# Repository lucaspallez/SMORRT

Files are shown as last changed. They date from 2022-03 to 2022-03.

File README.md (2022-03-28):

# SMORRT
Smart Management of Rocket Recovery and Telemetry

Avionics PCB for High-Power Rocketry

Embedded Software for this board available here: https://github.com/lucaspallez/SMORRT_Software
Compatible Ground Station PCB: https://github.com/lucaspallez/GRUND

## Features
- Computation: Teensy 4.1
- Telemetry: RFM95W LoRa Module (with SMA connector)
- IMU: MPU 6050 Breakout
- Barometer: BMP 280 Breakout
- GPS: Ublox NEO-M8J Module (with SMA connector)
- Data logging: 1Mbit FRAM IC + Teensy SD Card slot with locking screw
- Power Output: 4 MOSFET Pyro outputs with E-match detection, 2 Servo compatible (via PWM)
- Battery Management: 2x 1s Li-Ion Battery chargers
- Power Inputs: 2x Redundant 1s Li-Ion Battery connectors + 1x 12V Battery connector for power
- Arming: 1x Main external arm switch + 1x Power out external arm switch
- Status Indicators: 5x User programmable LEDs, 1x Buzzer
- Battery voltage readings

## Changes planned:
- Reduce the physical size to fit in smaller diameter rockets

## Documentation

Designed with KiCAD 5.5

TODO

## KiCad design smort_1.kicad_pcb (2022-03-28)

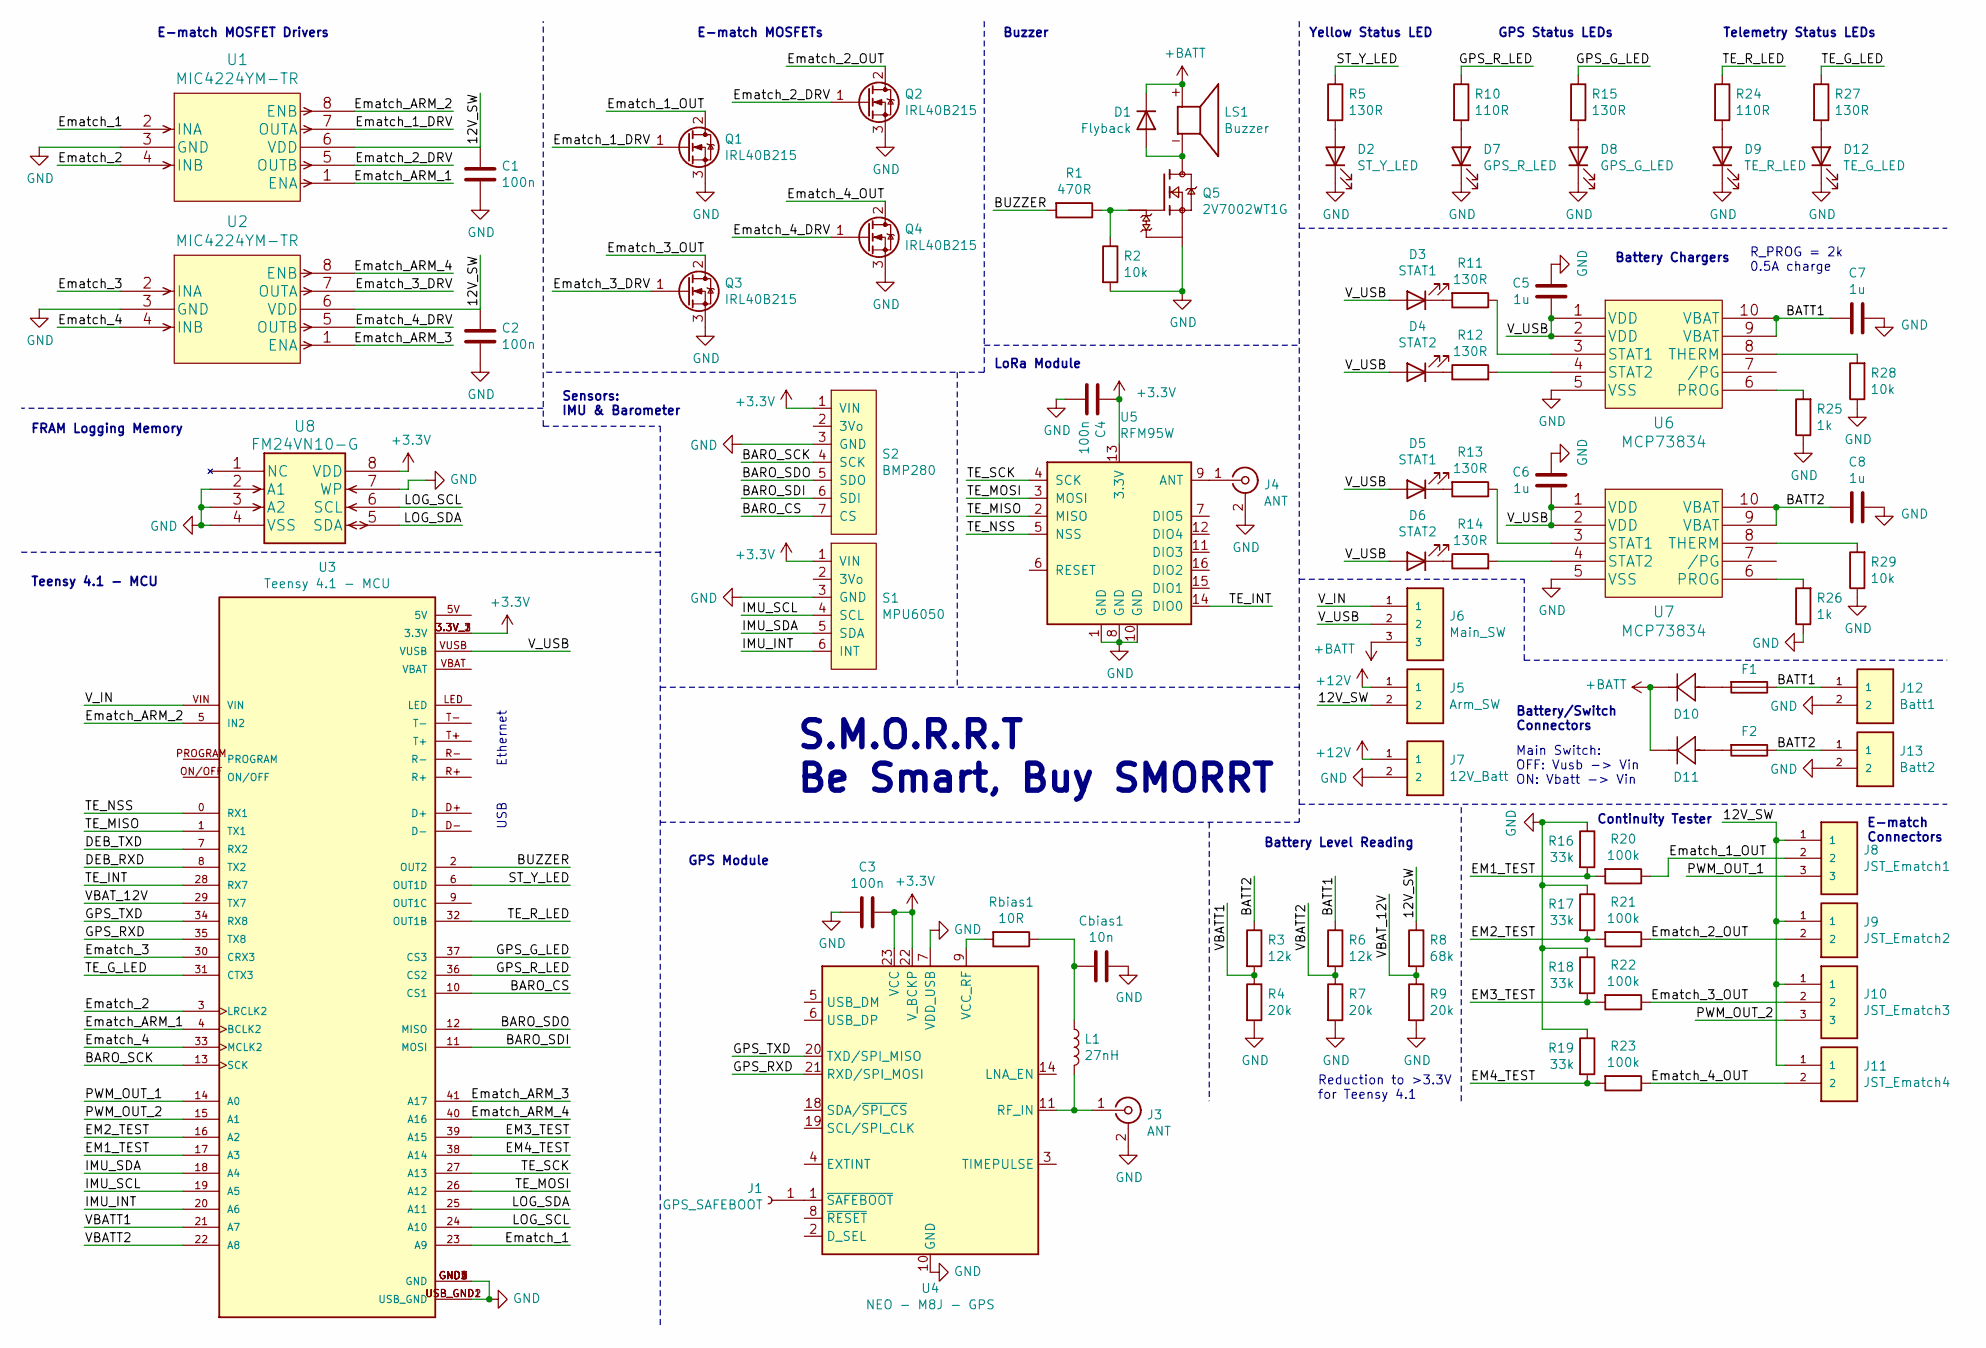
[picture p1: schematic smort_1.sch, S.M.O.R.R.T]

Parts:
C1, C2, C3, C4: 100n; C_0805_2012Metric
C5, C6, C7, C8: 1u; C_0805_2012Metric
Cbias1: 10n; C_0805_2012Metric
D1: Flyback; D_SOD-123F
D2: ST_Y_LED; LED_0805_2012Metric_Pad1.15x1.40mm_HandSolder
D3, D5: STAT1; LED_0805_2012Metric_Pad1.15x1.40mm_HandSolder
D4, D6: STAT2; LED_0805_2012Metric_Pad1.15x1.40mm_HandSolder
D7: GPS_R_LED; LED_0805_2012Metric_Pad1.15x1.40mm_HandSolder
D8: GPS_G_LED; LED_0805_2012Metric_Pad1.15x1.40mm_HandSolder
D9: TE_R_LED; LED_0805_2012Metric_Pad1.15x1.40mm_HandSolder
D10: BATT1; LSM115JE3&slash_TR13
D11: BATT2; LSM115JE3&slash_TR13
D12: TE_G_LED; LED_0805_2012Metric_Pad1.15x1.40mm_HandSolder
F1, F2: Fuse; Fuse_0805_2012Metric
J1: GPS_SAFEBOOT; PinHeader_1x01_P2.54mm_Vertical
J3, J4: ANT; LINX_CONSMA020.062-G
J5: Arm_SW; JST_S2B-PH-K-S(LF)(SN)
J6: Main_SW; JST_S3B-PH-K-S(LF)(SN)
J7: 12V_Batt; JST_S2B-PH-K-S(LF)(SN)
J8: JST_Ematch1; JST_S3B-PH-K-S(LF)(SN)
J9: JST_Ematch2; JST_S2B-PH-K-S(LF)(SN)
J10: JST_Ematch3; JST_S3B-PH-K-S(LF)(SN)
J11: JST_Ematch4; JST_S2B-PH-K-S(LF)(SN)
J12: Batt1; JST_S2B-PH-K-S(LF)(SN)
J13: Batt2; JST_S2B-PH-K-S(LF)(SN)
L1: 27nH; L_0805_2012Metric
LS1: Buzzer; CUI_CMI-9605IC-0380T; PARTREV 1.0
Q1, Q2, Q3, Q4: IRL40B215; TO-220F-3_Vertical
Q5: 2V7002WT1G; SOT65P220X100-3N; PARTREV 6
R1: 470R; R_0805_2012Metric
R2, R28, R29: 10k; R_0805_2012Metric
R3, R6: 12k; R_0805_2012Metric
R4, R7, R9: 20k; R_0805_2012Metric
R5, R11, R12, R13, R14, R15, R27: 130R; R_0805_2012Metric
R8: 68k; R_0805_2012Metric
R10, R24: 110R; R_0805_2012Metric
R16, R17, R18, R19: 33k; R_0805_2012Metric
R20, R21, R22, R23: 100k; R_0805_2012Metric
R25, R26: 1k; R_0805_2012Metric
Rbias1: 10R; R_0805_2012Metric
S1: MPU6050; MPU_6050_Breakout
S2: BMP280; BMP_280_Breakout
U1, U2: MIC4224YM-TR
U3: Teensy 4.1 - MCU; MODULE_DEV-16771; PARTREV 4.1
U4: NEO - M8J - GPS; ublox_NEO
U5: RFM95W; HOPERF_RFM9XW_SMD
U6, U7: MCP73834; MCP73834-NVI&slash_UN
U8: FM24VN10-G

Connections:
+3V3: C3.1, C4.1, S1.1 (VIN), S2.1 (VIN), U3.3.3V_1 (3.3V), U3.3.3V_2 (3.3V), U3.3.3V_3 (3.3V), U4.22 (V_BCKP), U4.23 (VCC), U5.13 (3.3V), U8.8 (VDD)
+12V: J5.1, J7.1
+BATT: D1.1 (K), D10.1, D11.1, J6.3, LS1.P
/12V_SW: C1.1, C2.1, J5.2, J8.1, J9.1, J10.1, J11.1, R8.1, U1.6 (VDD), U2.6 (VDD)
/BARO_CS: S2.7 (CS), U3.10 (CS1)
/BARO_SCK: S2.4 (SCK), U3.13 (SCK)
/BARO_SDI: S2.6 (SDI), U3.11 (MOSI)
/BARO_SDO: S2.5 (SDO), U3.12 (MISO)
/BATT1: C7.1, F1.1, J12.1, R6.1, U6.9 (VBAT), U6.10 (VBAT)
/BATT2: C8.1, F2.1, J13.1, R3.1, U7.9 (VBAT), U7.10 (VBAT)
/BUZZER: R1.2, U3.2 (OUT2)
/DEB_RXD: U3.8 (TX2)
/DEB_TXD: U3.7 (RX2)
/EM1_TEST: R16.2, R20.2, U3.17 (A3)
/EM2_TEST: R17.2, R21.2, U3.16 (A2)
/EM3_TEST: R18.2, R22.2, U3.39 (A15)
/EM4_TEST: R19.2, R23.2, U3.38 (A14)
/Ematch_1: U1.2 (INA), U3.23 (A9)
/Ematch_1_DRV: Q1.1 (G), U1.7 (OUTA)
/Ematch_1_OUT: J8.2, Q1.2 (D), R20.1
/Ematch_2: U1.4 (INB), U3.3 (LRCLK2)
/Ematch_2_DRV: Q2.1 (G), U1.5 (OUTB)
/Ematch_2_OUT: J9.2, Q2.2 (D), R21.1
/Ematch_3: U2.2 (INA), U3.30 (CRX3)
/Ematch_3_DRV: Q3.1 (G), U2.7 (OUTA)
/Ematch_3_OUT: J10.2, Q3.2 (D), R22.1
/Ematch_4: U2.4 (INB), U3.33 (MCLK2)
/Ematch_4_DRV: Q4.1 (G), U2.5 (OUTB)
/Ematch_4_OUT: J11.2, Q4.2 (D), R23.1
/Ematch_ARM_1: U1.1 (ENA), U3.4 (BCLK2)
/Ematch_ARM_2: U1.8 (ENB), U3.5 (IN2)
/Ematch_ARM_3: U2.1 (ENA), U3.41 (A17)
/Ematch_ARM_4: U2.8 (ENB), U3.40 (A16)
/GPS_G_LED: R15.1, U3.37 (CS3)
/GPS_RXD: U3.35 (TX8), U4.21 (RXD/SPI_MOSI)
/GPS_R_LED: R10.1, U3.36 (CS2)
/GPS_TXD: U3.34 (RX8), U4.20 (TXD/SPI_MISO)
/IMU_INT: S1.6 (INT), U3.20 (A6)
/IMU_SCL: S1.4 (SCL), U3.19 (A5)
/IMU_SDA: S1.5 (SDA), U3.18 (A4)
/LOG_SCL: U3.24 (A10), U8.6 (SCL)
/LOG_SDA: U3.25 (A11), U8.5 (SDA)
/PWM_OUT_1: J8.3, U3.14 (A0)
/PWM_OUT_2: J10.3, U3.15 (A1)
/ST_Y_LED: R5.1, U3.6 (OUT1D)
/TE_G_LED: R27.1, U3.31 (CTX3)
/TE_INT: U3.28 (RX7), U5.14 (DIO0)
/TE_MISO: U3.1 (TX1), U5.2 (MISO)
/TE_MOSI: U3.26 (A12), U5.3 (MOSI)
/TE_NSS: U3.0 (RX1), U5.5 (NSS)
/TE_R_LED: R24.1, U3.32 (OUT1B)
/TE_SCK: U3.27 (A13), U5.4 (SCK)
/VBATT1: R3.2, R4.1, U3.21 (A7)
/VBATT2: R6.2, R7.1, U3.22 (A8)
/VBAT_12V: R8.2, R9.1, U3.29 (TX7)
/V_IN: J6.1, U3.VIN
/V_USB: C5.1, C6.1, D3.2 (A), D4.2 (A), D5.2 (A), D6.2 (A), J6.2, U3.VUSB, U6.1 (VDD), U6.2 (VDD), U7.1 (VDD), U7.2 (VDD)
GND: C1.2, C2.2, C3.2, C4.2, C5.2, C6.2, C7.2, C8.2, Cbias1.2, D2.1 (K), D7.1 (K), D8.1 (K), D9.1 (K), D12.1 (K), J3.2 (Ext), J4.2 (Ext), J7.2, J12.2, J13.2, Q1.3 (S), Q2.3 (S), Q3.3 (S), Q4.3 (S), Q5.2, R2.2, R4.2, R7.2, R9.2, R16.1, R17.1, R18.1, R19.1, R25.1, R26.1, R28.1, R29.1, S1.3 (GND), S2.3 (GND), U1.3 (GND), U2.3 (GND), U3.GND1 (GND), U3.GND2 (GND), U3.GND3 (GND), U3.GND4 (GND), U3.GND5 (GND), U3.USB_GND1 (USB_GND), U3.USB_GND2 (USB_GND), U4.7 (VDD_USB), U4.10 (GND), U4.12 (GND), U4.13 (GND), U4.24 (GND), U5.1 (GND), U5.8 (GND), U5.10 (GND), U6.5 (VSS), U7.5 (VSS), U8.2 (A1), U8.3 (A2), U8.4 (VSS), U8.7 (WP)
unnamed: Cbias1.1, L1.1, Rbias1.1
unnamed: D1.2 (A), LS1.N, Q5.3
unnamed: D2.2 (A), R5.2
unnamed: D3.1 (K), R11.2
unnamed: D4.1 (K), R12.1
unnamed: D5.1 (K), R13.2
unnamed: D6.1 (K), R14.1
unnamed: D7.2 (A), R10.2
unnamed: D8.2 (A), R15.2
unnamed: D9.2 (A), R24.2
unnamed: D10.2, F1.2
unnamed: D11.2, F2.2
unnamed: D12.2 (A), R27.2
unnamed: J1.1, U4.1 (~SAFEBOOT)
unnamed: J3.1 (In), L1.2, U4.11 (RF_IN)
unnamed: J4.1 (In), U5.9 (ANT)
unnamed: Q5.1, R1.1, R2.1
unnamed: R11.1, U6.3 (STAT1)
unnamed: R12.2, U6.4 (STAT2)
unnamed: R13.1, U7.3 (STAT1)
unnamed: R14.2, U7.4 (STAT2)
unnamed: R25.2, U6.6 (PROG)
unnamed: R26.2, U7.6 (PROG)
unnamed: R28.2, U6.8 (THERM)
unnamed: R29.2, U7.8 (THERM)
unnamed: Rbias1.2, U4.9 (VCC_RF)

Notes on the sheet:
Telemetry Status LEDs
GPS Status LEDs
Yellow Status LED
E-match MOSFET Drivers
E-match MOSFETs
LoRa Module
Ethernet
USB
Teensy 4.1 - MCU
GPS Module
Battery Chargers
Main Switch: OFF: Vusb -> Vin ON: Vbatt -> Vin
Battery/Switch Connectors
Buzzer
Sensors: IMU & Barometer
R_PROG = 2k 0.5A charge
Battery Level Reading
Reduction to >3.3V for Teensy 4.1
FRAM Logging Memory
S.M.O.R.R.T Be Smart, Buy SMORRT
E-match Connectors
Continuity Tester

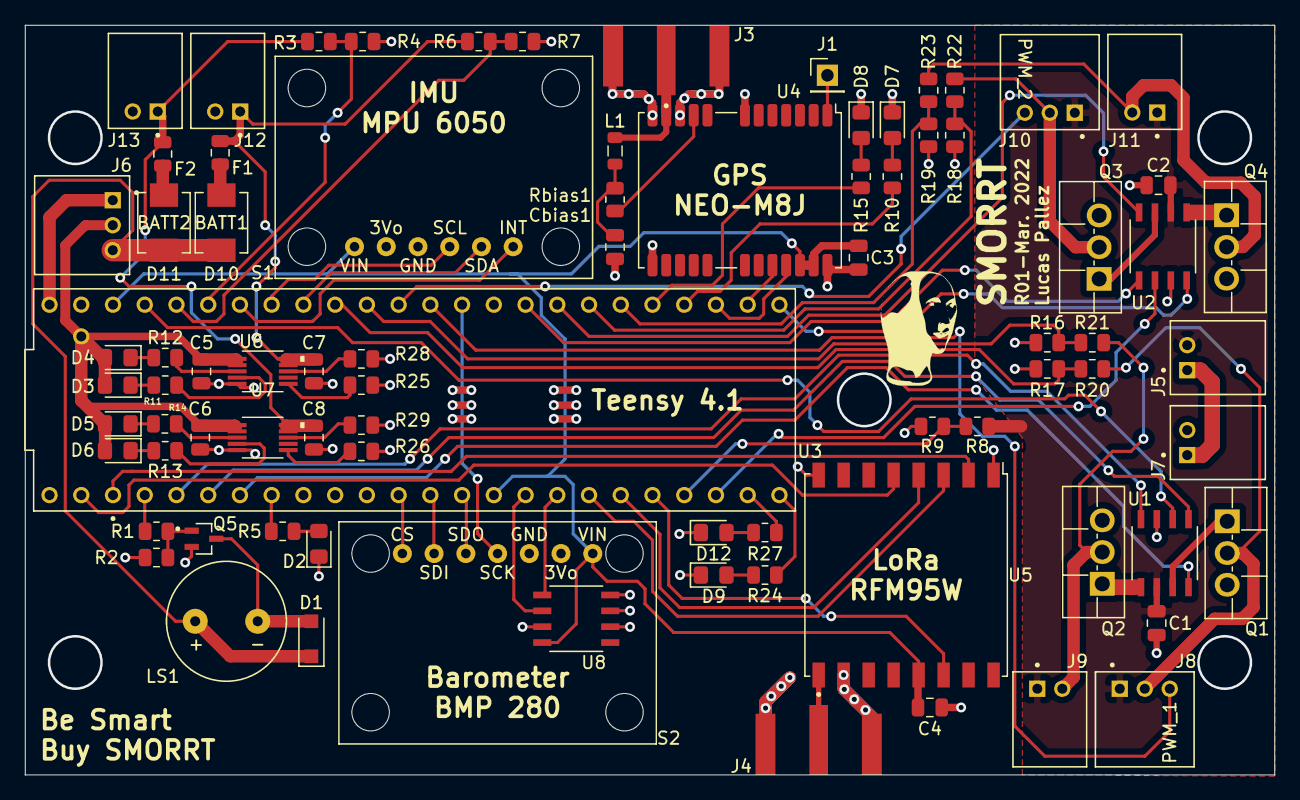
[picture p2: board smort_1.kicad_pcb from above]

Board: 2 copper layers, 100.0 x 60.0 mm, 82 parts (0 on the bottom side), 82 nets.

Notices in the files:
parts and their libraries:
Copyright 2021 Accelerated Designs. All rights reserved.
